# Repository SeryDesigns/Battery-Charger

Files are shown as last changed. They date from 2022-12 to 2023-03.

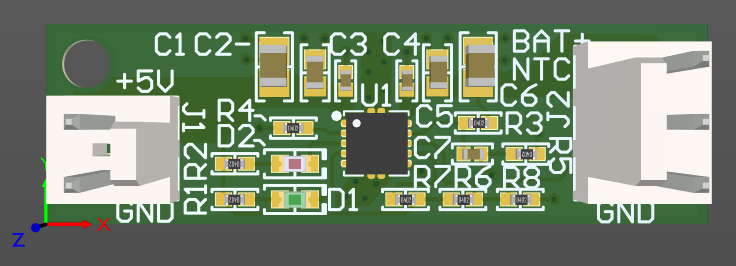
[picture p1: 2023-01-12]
docs/PCB top.png

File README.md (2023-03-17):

# Battery-Charger

## Project status 
Manufactured, assembled, tested

## Project overview

Li-Ion battery charger, based on BQ24060 IC, this simple PCB takes 5V as input and charges
a 3.7V Li-Ion battery. \
The charger has output short circuit protection and optional thermal protection. \
It can charge a battery with current up to 1A (the charging current is set by a resistor), the PCB works without a problem at charging current up to ~0.7A, at higher current without heatsink or cooling the IC heats up and enters thermal protection, cycling the charging on and off.

There are 2 indication LEDs for status, green and red LEDs -
| LED color | Charger state |
|---|---|
| Green + Red | Precharge in progress |
| Red | Fast charge in progress |
| Green | Fully charged |
| None | Power off / suspended / fault |

The dimension of the PCB are 33mm X 10mm, it is a 2 layers PCB with compoenents assembled only on the TOP layer

Top view - \

\
Bottom view -  \


I've created a short time lapse video of the design process, you can click the link below to check it out on my YouTube channel \
Battery charger PCB design in 5 minutes (time lapse) (https://youtu.be/Mz6wxAzDqSU)

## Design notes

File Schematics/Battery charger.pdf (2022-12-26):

# Battery charger

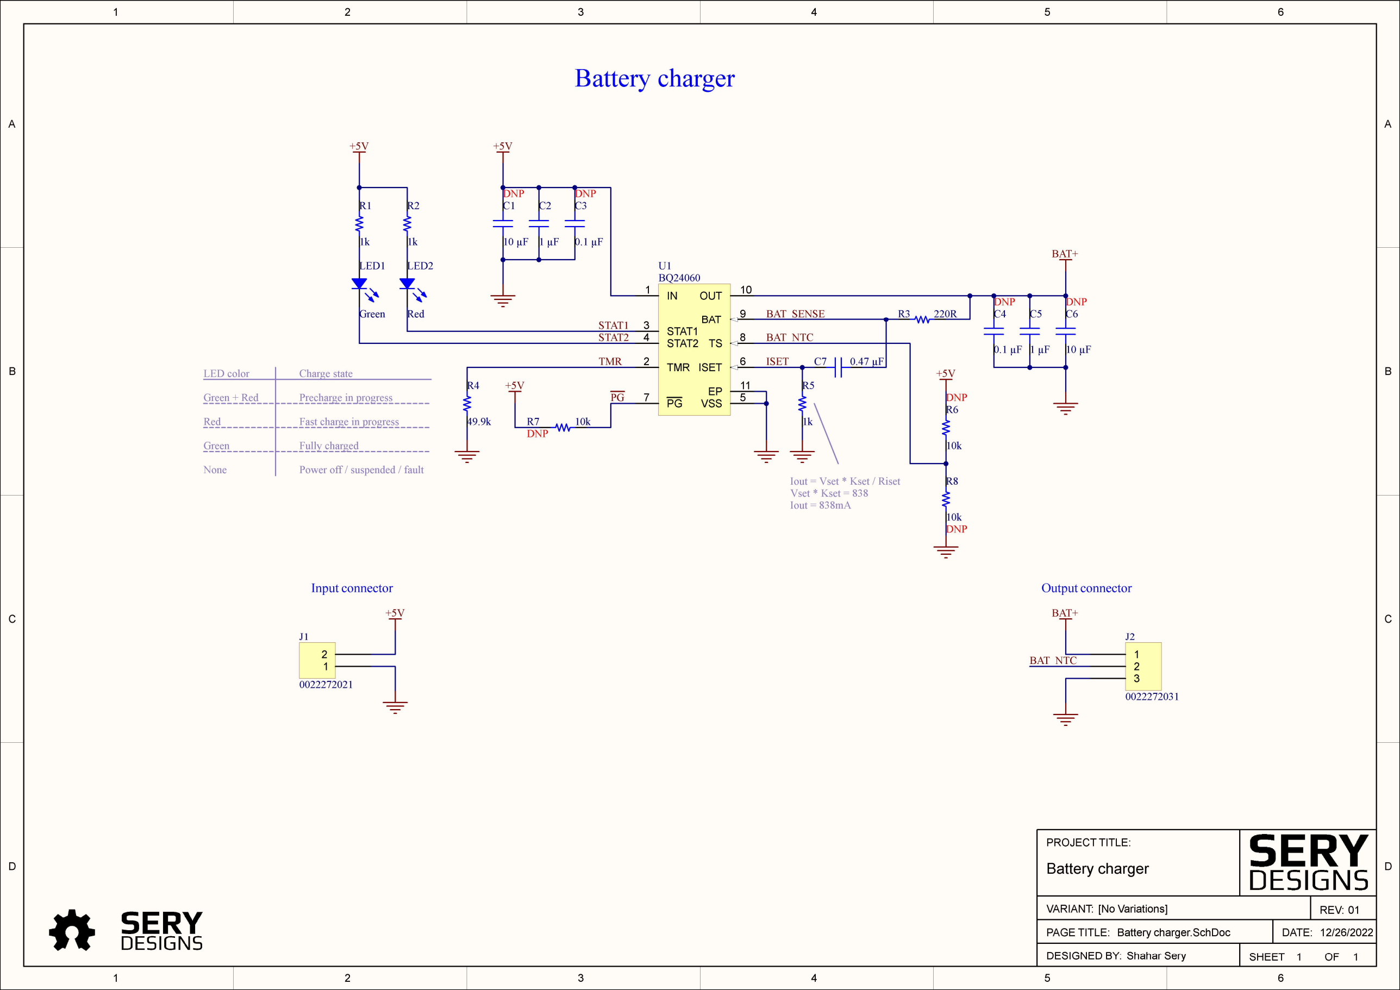
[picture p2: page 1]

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
Battery charger.SchDoc

SHEET | OF 1

REV:

PROJECT TITLE:

## Battery charger

1

VARIANT:

PAGE TITLE: | DATE:

DESIGNED BY:

[No Variations] | 01
| 12/26/2022

Shahar Sery

IN 1

TMR 2

STAT1 3
STAT2 4
VSS | 5
ISET | 6

PG 7

TS | 8
BAT | 9
OUT | 10
EP | 11

U1
BQ24060

+5V

### 10 µF

C1

### 1 µF

C2

### 0.1 µF

C3

BAT+

### 10 µF

C6

### 1 µF

C5

### 0.1 µF

C4

1k

R1

+5V

1k

R2

LED2

Red

LED1

Green | 220R R3
C7 | 0.47 µF

1k

R5

49.9k

R4

R7 | 10k

+5V

10k

R6

10k

R8

+5V

DNP | DNP
DNP | DNP

DNP

DNP

DNP

Iout = Vset * Kset / Riset Vset * Kset = 838
Iout = 838mA
LED color | Charge state
Green + Red Red Green None | Precharge in progress
| Fast charge in progress
| Fully charged
| Power off / suspended / fault

BAT_SENSE

BAT_NTC

ISET

STAT1
STAT2

TMR

PG

1

2

J1

0022272021

1
2
3

J2

0022272031

+5V | BAT+

BAT_NTC

Input connector | Output connector

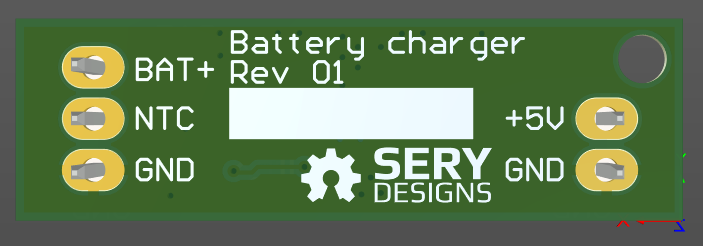
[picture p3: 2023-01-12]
docs/PCB bottom.png

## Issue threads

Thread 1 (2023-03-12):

Documentation Issue for Green LED

luckyhacky, 2023-03-12:
Status LED Green should be "Status Done" according to datasheet.
In Readme there is written "Green | Fast charge in progress".
Seems to be a copy paste issue.

Thanks for your work :)

SeryDesigns, 2023-03-17:
Fixed, thanks for noticing.
I'm glad you found my work helpful :)

Closed 2023-03-17.
